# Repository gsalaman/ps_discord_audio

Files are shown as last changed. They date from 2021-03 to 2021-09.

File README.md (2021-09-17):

# Playstion/Discord Audio Mixer Project
This project provides a box that mixes together Audio and Microphone from both Playstation and Discord sources into a single headset. 

Quick Links:
* [Project Proposal](https://docs.google.com/document/d/1kymvg32hHtV9tEDY5p4hLi2L7wjIxDkjKmbJ4Tb4wR8/edit?usp=sharing)
* [Schedule](https://docs.google.com/spreadsheets/d/1bOIFvx7hpu0AlzfgVh9q8kjzmG0GHja3u-9B9gV9Qrc/edit?usp=sharing)
* [Journal](https://github.com/gsalaman/ps_discord_audio/blob/main/journal.md)
* [Design Document](https://docs.google.com/document/d/1ipFKIDMNCPuamUNVuetQo5jEzDj95vrXEs8RwQP3rsA/edit?usp=sharing)
* [Test Plan](https://docs.google.com/document/d/1uWEIeDPq-ZtmWTCWSF0HcOkNuqYgmgUuFNPxV6GTQaU/edit?usp=sharing)
* [Software Source (Arduino)](https://github.com/gsalaman/ps_discord_audio/tree/main/ghost_case_v1)
* [Hardware Source (Kicad & Gerber)](https://github.com/gsalaman/ps_discord_audio/tree/main/audio_quad_minimal)
* [User's Guide](https://docs.google.com/document/d/133C6y8KPKBfXd7hmt4fOLVRxKzTunB-pMatfn9UUioA/edit?usp=sharing)
* [Project Presentation](https://docs.google.com/presentation/d/1Z-V4jjkeFAulbqQNvLp17moSJGjj3tiSwEFrkb0hboE/edit?usp=sharing)

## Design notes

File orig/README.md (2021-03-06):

# ps_discord_audio
My notes for a playstation/discord audio mixer

Plugs are TRRS.  From the specs, sometimes Shield is GND, sometimes Mic.  Gonna need to measure phones (android and apple), PC, and playstation.  Just in case, could design in a jumper to route those two...

```
Mac, HTC headset, HTC phone:
------------------
Tip is L audio
R1  is R audio
R2 is GND
S  is Mic
```

## Simple Audio Mix:  a bunch of 470 ohm resistors:


## Next Steps
I'm gonna want gain.  I *could* use a 324, but the LM386 looks like it's custom made for what I want.  Cool amplifier link here:
https://www.circuitbasics.com/build-a-great-sounding-audio-amplifier-with-bass-boost-from-the-lm386/

Prototype with two channels, then summed with the resistors as above.  Implementation will have a dual gang potentiometers to hit both channels.

Will need to make a bunch of TRRS cables.  Buying them is $10 a pop, and each setup needs 2...or maybe even 3 if their headset doesn't have one.
Could do cable connected directly outta box to Discord and Playstation Controller, but I think I like the connector instead...seems like it's more robust as the cable will come out under stress (rather than breaking)

Want Mute Switch.

And, if we're doing this, I should have cool lights...an ATTINY85 and a couple LEDs.

### Proto parts needed
* TRRS Female connectors.  Have 7.
* Cable Parts:
  * TRRS Male Connectors.  If I churn out 10 boxes, I need 20 cables or 40 connectors. Start smaller.
  * Heat shrink
  * 4-wire cabyle itself
  * What's the cost effectiveness?
* LM386.   2 for proto.  JLCPCB for after that.
* Some sort of Mute Switch.  Can use SPDT for starters; 10 others for production.
* 2 Dual-Gang pots for Proto.  10 for production.
* 1000 uF cap x2
* .1 uF cap x4
* 10k resistor x2
* Have the 470 resistors for signal summming.
* 470 pF Cap x2
* 100 uF Electrolytic cap x2
* 10 uF Electrolytic cap x4

## Test #1
Build 1 of the "simple" amplifier circuit.  How does it sound?  Should be popping etc.  Gain of 20 okay?

## Test #2
Now make 2 of them, chained together with the 470 ohms.  Seperate gain works?  Can I drive both off one batt?  Can I move the 1000uF cap to *after* the sum?

## Test #3
More advanced circuit...build up both.  Significant sound quality increase?  

## Test #4
4 circuits, mixing all 4 channels.  Dual Pots.  Can I still get away with one batt?

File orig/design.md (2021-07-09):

# Playstation/Discord Audio Mix Box Design

## High Level Overview

## Hardware
Since I'm making multiple boxes, I'm going to do the hardware board as a custom PCB.  The various blocks:
* Battery and Power switch
* Audio Mixing
* Light Control 
* Microphone Routing and Mute Switch

### Overall Schematic


Note that I've got two different grounds:  
*  GND for the audio signal
*  GNDREF for power
This should help isolate the audio from "pops and clicks" due to any fluctuations on the power circuit.

The top section is our audio mix circut; almost identical to the prototype version, with the exception that the Mic signal goes through a mute switch (SW1).  The other pole of this mute switch goes to the ATTINY85 processor.

The bottom section is our ATTINY85 processor, with power and LED.

### Component Selection
#### Battery
I'm going to use a standard 2032 coin cell.  The following battery holders are available on Amazon:
https://www.amazon.com/gp/product/B08SQJJJNK/ref=ppx_yo_dt_b_asin_title_o09_s00?ie=UTF8&psc=1

#### Audio Cables and Jacks
All of the audio cables are going to be TRRS cables (Tip/Ring/Ring/Shield).  The following jacks are available on Amazon:
https://www.amazon.com/gp/product/B089222S84/ref=ppx_yo_dt_b_asin_title_o07_s00?ie=UTF8&psc=1

The pinout is as follows:
| pin | name | color | 
|-----|-----|-----|
| 2 | L | white |
| 3 | R | red |
| 4 | Gnd | Black |
| 1 | Mic | Green |

```
 2  3  4  1  ___
 __ __ __ __|
(__|__|__|__|
            |___
            
```

#### Power Switch
I'm using a simple SPST switch for power:
https://www.amazon.com/gp/product/B08JYV8HZ7/ref=ppx_yo_dt_b_asin_title_o01_s00?ie=UTF8&psc=1

#### Mute Switch
I need the mute switch to do two things:
* break the microphone path
* give the ATTINY a signal to detect whether we're muted or not.

Because of this, I'm choosing a Dual-Pole-Single-Throw switch.  One end goes through the Mic path, one end goes to the ATTINY.
https://www.amazon.com/gp/product/B07QS8K8T2/ref=ppx_yo_dt_b_asin_title_o09_s00?ie=UTF8&psc=1

Note that the ATTINY does not have pull-up resistors on it's input, so I've got R5 on the board for that purpose.

#### LED
I'm using a custom board with a single WS2812 LED.  It's able to be driven by the coin cell and the ATTINY.  The WS2812 will let me change colors on the LED.

### PCB Layout
The final PCB layout is as follows:


Note I'm only going Through-Hole parts here; no SMT assembly from the PCB vendor.

## Software
The ATTINY will have two modes of operation:
* When the mute switch is active (Muted), it'll blink the LED red.
* When the mute switch is not active (Not Muted), it'll cycle the LED through colors.

I'll be using the Arduino environment to program the ATTINY85.

### High Level Software Overview
I'll use Adafruit's NeoPixel library to program the LED.  

I'm going to use a global "tick_number" indicator to count time.   

I'll have globals for the Red/Green/Blue pixel values for when we're cycling through colors.  

The "setup" function will set up the  pins for Mute and LED.  

The "loop" function will read the Mute button, and choose between the following functions:
* Flash the LED red (muted)
* cycle through colors (non-muted)

"Loop" will also need to keep track of the last state of the mute button.  This is because when we first turn OFF mute (Un-mute), we want the cycle colors to reset to a known starting point.

### Muted Operation
We'll use the "tick_number" and a modulus funcition to alternate between setting the LED to all red or off.  I'll experiement with time values to see what looks good.

### Un-Muted Operatoin
This one will be a little tricker.  Here's the cycle algorithm:
```
Start with the LED Blue.
Step 1: Slowly decrease the Blue RGB value and increase the Green RGB value until the LED is all Green.
Step 2: Slowly decrease the Green RGB value and increase the Red RGB value until the LED is all Red.
Step 3:  Slowly Decrease the Red RGB value and increase the Blue RGB value until the LED is all Blue.
```
To determine which "step" we're on, I'll cycle the tick number.  Since each color value is going from 255 to 0 (or vice versa), I have 256 "ticks" in each step.

## Plastics
I'm going to design the case in three pieces:
* The "shell" will be the walls and the top, with holes for switches, heat-sets (to attach the bottom), jacks and the ghost.  I'll label the Jacks via embossed letters.
* The "bottom" will be a simple rectange that gets screwed onto the bottom of the case (and gives the user access to replacing the battery).
* The "Ghost" will be a contrasting color, modelled after destiny's Ghost.  I'll use a seperate piece of diffusing acrylic (laser-cut) to "spread out" the light of the led.  This will be glued onto the top.

Onshape files can be found here:
https://cad.onshape.com/documents/8eac8258773643f40666c139/w/5a93e26a0a6b1984f3ee80b1/e/b21e37a20e72b8d13801b5df

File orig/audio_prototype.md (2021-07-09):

# Prototyping Notes and Plan

Before I jump into my design, there are some prototyping things I need to do.

I'm comfortable with the ATTINY driving an LED and also using a mute switch.  Ready to go to design on those.

I need to figure out how to mix the audio signals together.  I have two options, listed below.

## Prototype Plan
### Simple Audio Mix:  a bunch of 470 ohm resistors
The easiest solution is to do passive mixing...basically connecting each channel together with resistors.  Looking online, the resisitor value is dependent on the output impedence, and looks like 470 ohm will do the trick for my headphone example.  
Here is the circuit:


Pros:  Very simple!  Not too many components.  Doesn't require power.

Cons:  I'm going to lose a little volume from each channel.

### Mix with Gain
If I want to add gain to the system, I'm going to need an amplifier.  In the past I've used a generic LM324 Op Amp, but the LM386 looks like it's custom made for what I want.  Cool amplifier link here:
https://www.circuitbasics.com/build-a-great-sounding-audio-amplifier-with-bass-boost-from-the-lm386/

I'm going to do a bread-boarded prototype with two channels, then summed with the resistors as above.  Implementation will have a dual gang potentiometers to hit both channels.

Pros:  able to control gain via the knobs on the box rather than going to PS & Discord to seperately tweak the levels.

Cons:  MUCH more complicated.  Requires a bigger battery to drive (9v?).

## Prototype Results:
* Simple audio mix worked well.  Audio loss was able to be compensated by Discord and PS apps on either side.
* The gain prototype was cool!  May go this route for a phase 2, but for now, I'm gonna go with the simpler solution.

## Next Step:  Write design document.

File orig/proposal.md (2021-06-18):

# Playstation/Discord Audio Mixer Box

## Problem Statement
I'm an avid "Destiny" gamer.  This game spans multiple platforms, and I've got people I play with on both the PC and Playstation platforms.
Communication is key when running this game; there are actions that need to be communicated precisely.  While Desitiny supports an "in-game" chat, 
the quality of the voice is severly lacking.  Because of this, most Destiny players run a different application for voice chat:
* Discord for the PC
* "Party Chat" on the Playstation

There is currently no cross-play functionality.  If you are on a PC, you must play with other PC players; you can't play with people running Destiny on a Playstation.  
However, cross-play has been announced, and will arrive in September, allowing PC and Playstation players to play together.

The problem is that there is no cross-play voice chat functionality (except for the limited game-chat).  My proposal is to make a box that allows a Playstation player to 
hook into Discord, mixing the audio from both Discord and the Game into the player's headset.

## Proposed Implementation
System Block Diagram below:
Discord Box Block Diagram

The "Discord" box can be any device using Discord...phone, tablet, laptop, desktop, etc.

The audio channels will be mixed passively between the Playstation controller and Discord box.

Microphone signals only need to go to the Discord app, as we won't be using Playstation Party Chat.  While we could rely on mute from the Discord box, we'll implement a hardwired mute switch in the microphone path for convenience.

To "spice up" the look of the box, we're going to design in a Destiny "ghost" with a light-up eye.  We'll have a simple Microprocessor driving that eye with two modes:
* In normal mode, the colors will cycle.
* When the box is muted, the eye will flash red

To power this processor, we'll use a simple coin-cell battery.

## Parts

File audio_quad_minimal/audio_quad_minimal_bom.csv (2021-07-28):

Comment | Designator | Footprint | LCSC Part Number
.1 uF | C3,C4,C7,C8 | 603 | C14663
1000uF | C1,C2,C5,C6 | SMD-ECAP-10x10 | C249474
470 ohm | R2,R3,R4,R5 | 603 | C23179
10 ohm | R6,R7,R8,R9 | 603 | C22859
LM386 | U1,U2,U3,U4 | SOIC-8_3.9x4.9x1.27P | C23573
220 ohm | R1 | 603 | C22962
pwr_led | D1 | 805 | C84256

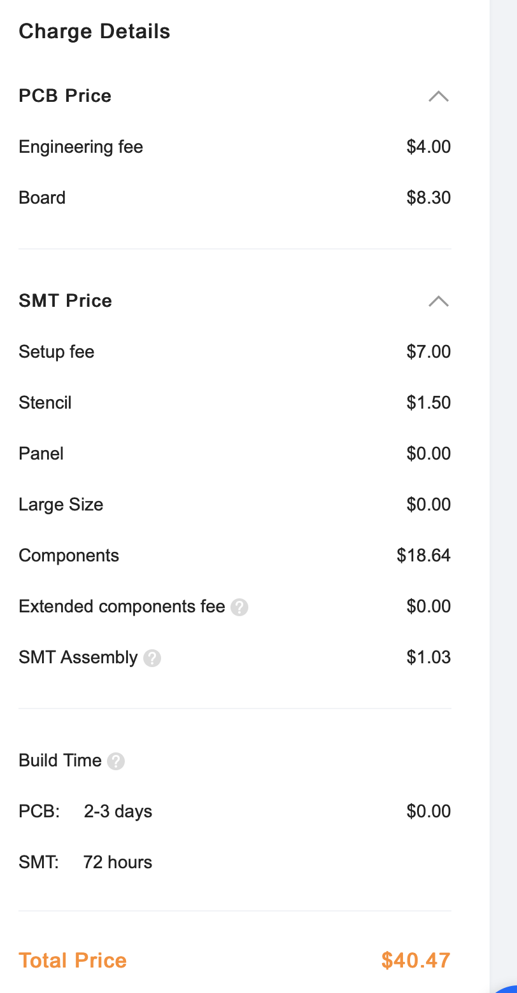
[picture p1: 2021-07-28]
audio_quad_minimal/cost for 10.png

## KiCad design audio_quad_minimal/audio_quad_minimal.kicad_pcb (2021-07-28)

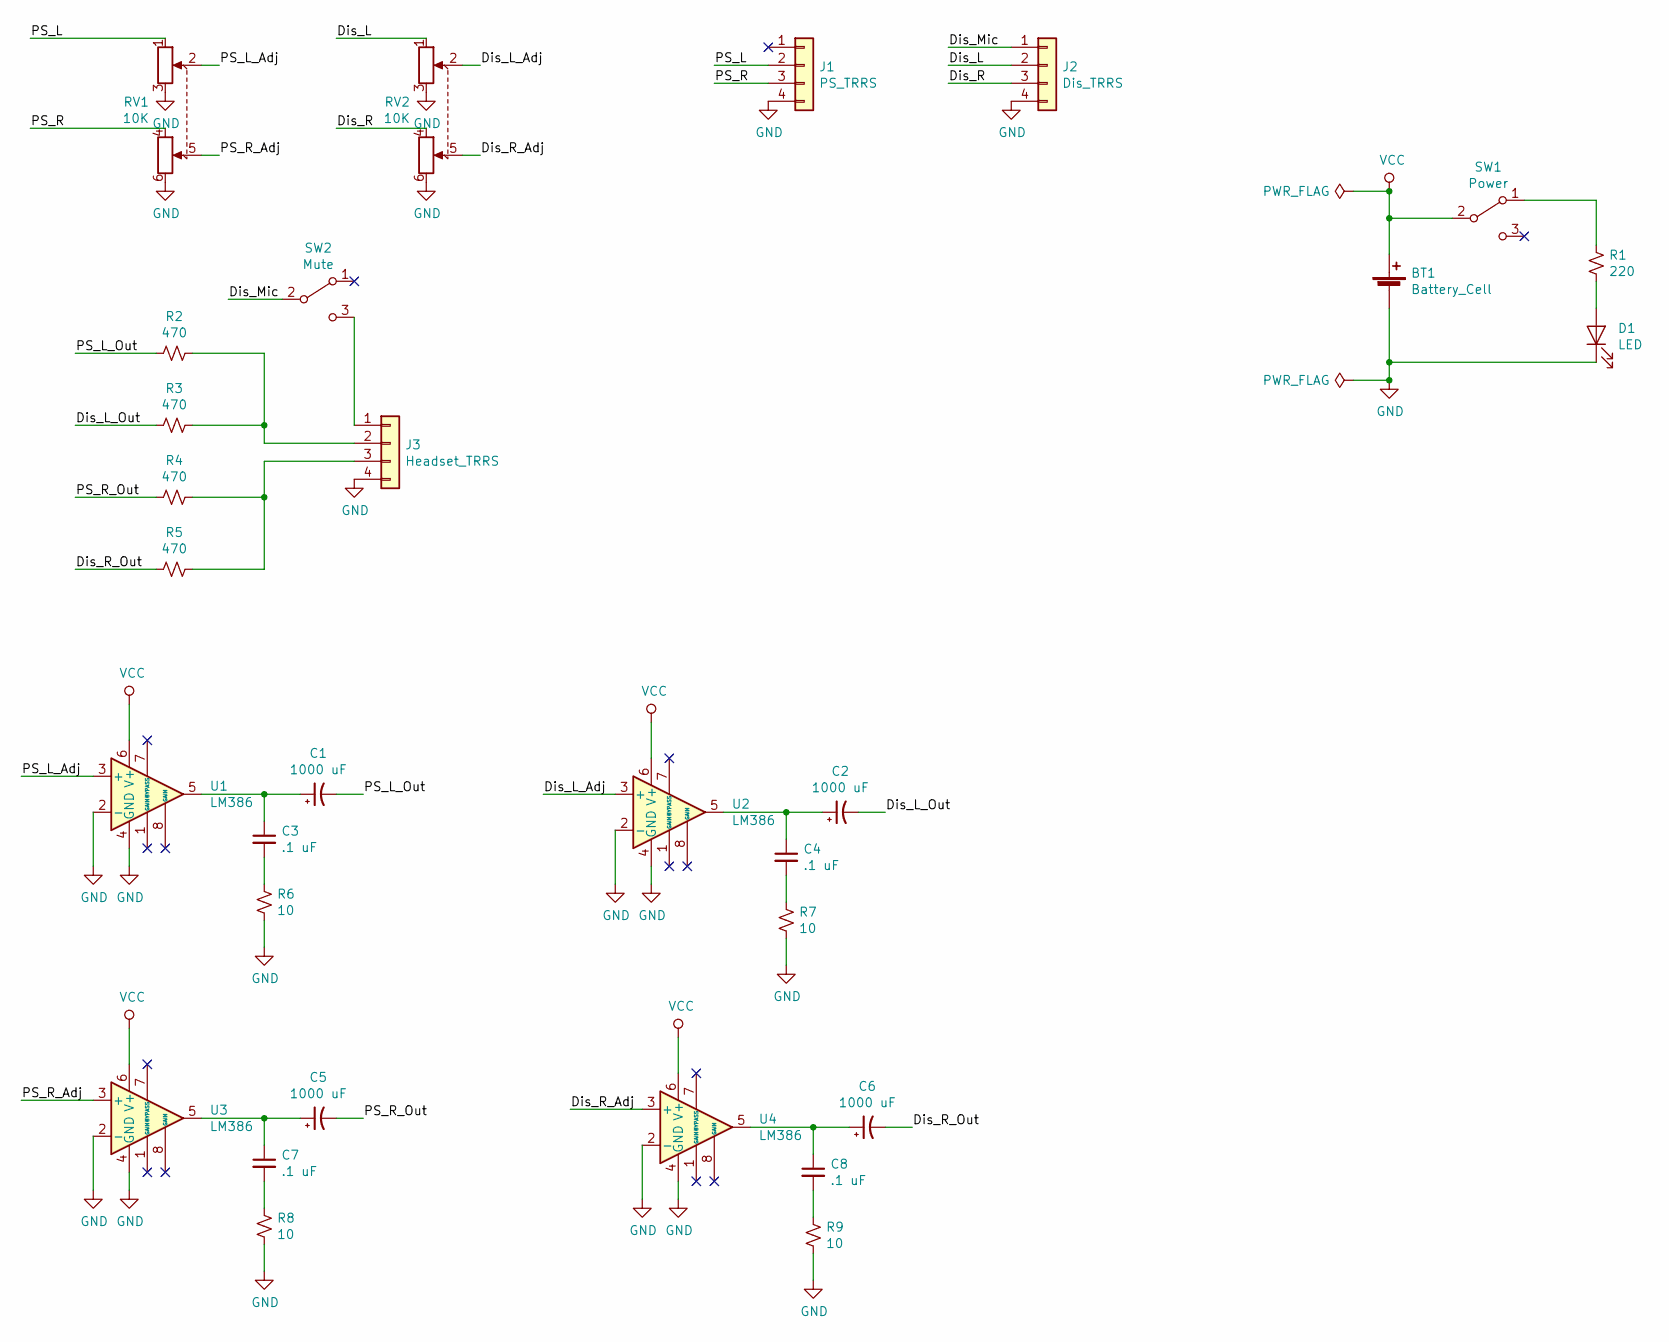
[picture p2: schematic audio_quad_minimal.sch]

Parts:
BT1: Battery_Cell; PinHeader_1x02_P2.54mm_Vertical
C1, C2, C5, C6: 1000 uF; CP_Elec_10x10
C3, C4, C7, C8: .1 uF; C_0603_1608Metric
D1: LED; LED_0805_2012Metric
J1: PS_TRRS; PinHeader_1x04_P2.54mm_Vertical
J2: Dis_TRRS; PinHeader_1x04_P2.54mm_Vertical
J3: Headset_TRRS; PinHeader_1x04_P2.54mm_Vertical
R1: 220; R_0603_1608Metric
R2, R3, R4, R5: 470; R_0603_1608Metric
R6, R7, R8, R9: 10; R_0603_1608Metric
RV1, RV2: 10K; PinHeader_2x03_P2.54mm_Vertical
SW1: Power; PinHeader_1x03_P2.54mm_Vertical
SW2: Mute; PinHeader_1x03_P2.54mm_Vertical
U1, U2, U3, U4: LM386; SOIC-8_3.9x4.9mm_P1.27mm

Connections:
/Dis_L: J2.2, RV2.1
/Dis_L_Adj: RV2.2, U2.3 (+)
/Dis_L_Out: C2.2, R3.2
/Dis_Mic: J2.1, SW2.2 (B)
/Dis_R: J2.3, RV2.4
/Dis_R_Adj: RV2.5, U4.3 (+)
/Dis_R_Out: C6.2, R5.2
/PS_L: J1.2, RV1.1
/PS_L_Adj: RV1.2, U1.3 (+)
/PS_L_Out: C1.2, R2.2
/PS_R: J1.3, RV1.4
/PS_R_Adj: RV1.5, U3.3 (+)
/PS_R_Out: C5.2, R4.2
GND: BT1.2 (-), D1.1 (K), J1.4, J2.4, J3.4, R6.2, R7.2, R8.2, R9.2, RV1.3, RV1.6, RV2.3, RV2.6, U1.2 (-), U1.4 (GND), U2.2 (-), U2.4 (GND), U3.2 (-), U3.4 (GND), U4.2 (-), U4.4 (GND)
unnamed: C1.1, C3.1, U1.5
unnamed: C2.1, C4.1, U2.5
unnamed: C3.2, R6.1
unnamed: C4.2, R7.1
unnamed: C5.1, C7.1, U3.5
unnamed: C6.1, C8.1, U4.5
unnamed: C7.2, R8.1
unnamed: C8.2, R9.1
unnamed: D1.2 (A), R1.2
unnamed: J3.1, SW2.3 (C)
unnamed: J3.2, R2.1, R3.1
unnamed: J3.3, R4.1, R5.1
unnamed: R1.1, SW1.1 (A)
VCC: BT1.1 (+), SW1.2 (B), U1.6 (V+), U2.6 (V+), U3.6 (V+), U4.6 (V+)

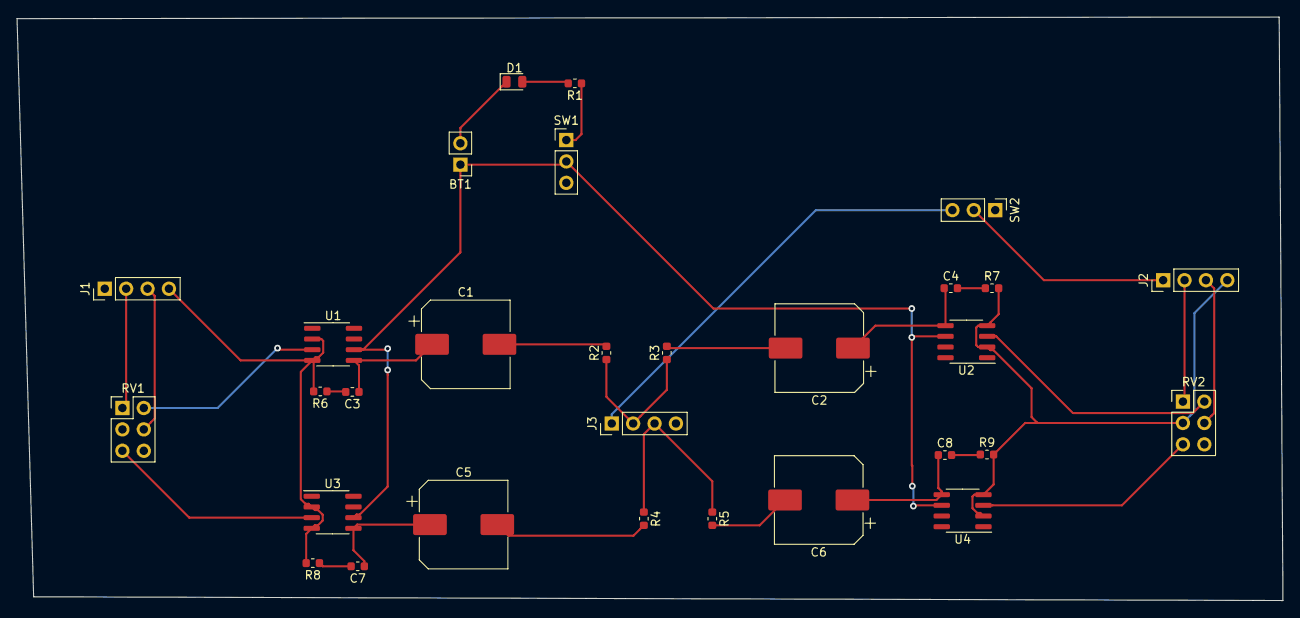
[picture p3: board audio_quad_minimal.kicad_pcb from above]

Board: 2 copper layers, 150.3 x 69.3 mm, 30 parts (0 on the bottom side), 28 nets.

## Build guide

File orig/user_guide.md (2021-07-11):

# Overview
top
topv2

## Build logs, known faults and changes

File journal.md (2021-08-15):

# 3/1/21
First order of buisness: see how the plugs are wired.  

From the specs, sometimes Shield is GND, sometimes Mic. Gonna need to measure phones (android and apple), PC, and playstation. Just in case, could design in a jumper to route those two.  Diagram below:

```
 T  R1 R2  S ___
 __ __ __ __|
(__|__|__|__|
            |___

Measured on my Mac and HTC headset:
------------------ 
Tip is L audio
R1  is R audio
R2 is GND
S  is Mic
```
I'm a little worried that the iPhone is gonna be wired differently, as Apple tends to do things their own way...but the Mac is wired the same as the android phone (and playstation controller), so that's less risk.  Will send a prototype out to Lamonte (who has iPhone) and let him test it.

# 3/4/21

Before I jump into my design, there are some prototyping things I need to do.

I'm comfortable with the ATTINY driving an LED and also using a mute switch.  Ready to go to design on those....I'm gonna reuse the same "cycle" code I've previously done for the ATTINY before, and add a second "flashing red" state for mute.  

I need to figure out how to mix the audio signals together.  I have two options, listed below.

### Simple Audio Mix:  a bunch of 470 ohm resistors
The easiest solution is to do passive mixing...basically connecting each channel together with resistors.  Looking online, the resisitor value is dependent on the output impedence, and looks like 470 ohm will do the trick for my headphone example.  
Here is the circuit:


Pros:  Very simple!  Not too many components.  Doesn't require power.

Cons:  I'm going to lose a little volume from each channel.

### Mix with Gain
If I want to add gain to the system, I'm going to need an amplifier.  In the past I've used a generic LM324 Op Amp, but the LM386 looks like it's custom made for what I want.  Cool amplifier link here:
https://www.circuitbasics.com/build-a-great-sounding-audio-amplifier-with-bass-boost-from-the-lm386/

I'm going to do a bread-boarded prototype with two channels, then summed with the resistors as above.  Implementation will have a dual gang potentiometers to hit both channels.

Pros:  able to control gain via the knobs on the box rather than going to PS & Discord to seperately tweak the levels.

Cons:  MUCH more complicated.  Requires a bigger battery to drive (9v?).

## Simple Audio Mix Prototype:
Picture of the breadboarded circuit:


Results: worked well.  Audio loss was able to be compensated by Discord and PS apps on either side...but there still was loss.

# 3/7/21
Next iteration: single channel gain stage combining.  Specifically, taking the R channel from two sources (PS and Discord), applying seperate gains (controlled by the two knobs), and then combining the output signal like in the previous experiment.  Picture of the breadboarded prototype:


Results:  worked fairly well....but going to two channels means circuitry gets a little more complicated...and I'm worried about pops and clicks (got a few just on the breadboard)  

Plan:  I'm gonna shelve this one, and proceed with the simple mix for our product.

# 3/11/21
Soldered up prototype to send out to Lamonte for iPhone testing:


# 3/20/21
Spun a simple case...pics below:




# 3/30/21
Prototype box mailed out to Lamonte!

# 4/2/21
Tested the box with Lamonte...me on the breadboarded version, him with the prototype via iPhone.

IT WORKED!!!

Now, time to spin the schematic via kicad.

# 4/10/21
Board spin complete; sent to JLCPCB.

# 4/11/21
Plastics thoughts:
* Gotta be able to get to the battery...meaning I want the bottom removable via heat-sets.
* Need to label the jacks.  In a pinch, I can do the label maker like with Lamonte's board...but I want something a little "better".  Gonna try embossing the letters vertically...I think the uPrint can deal with that.
* Ideally, I want the "ghost" a different color...meaning a different plastic print.  I'll design it in so that there's a "shelf" on the top for it to fit into....and I need a square hole for the LED board to shine through.
* For the ghost "eye", I'm just gonna cut a piece of 1/8 wood from the laser cutter (cheaper!) and glue it in place.  If I need it, I'll use a piece of that whiteish LED diffusing acrylic.

# 4/12/21
Stopped by Dawson:  printed outer shell.  Yellow is the color in the printer.

# 4/13/21
Shell happy...uPrint in use by others, so I printed the ghost on the Raise3D.  

Now I just need the boards to come back...

# 4/15/21
JLCPCB build complete...boards on their way back to me.

# 4/21/21
Got the boards back from JLCPCB!!!  Assembly pics below.

### The board:


### The other components:


Note that the rocker switch for the mute is already in the case...I did a test fit, as this one "snaps in".  Made soldering it a little more challenging...more on that below.

### The ghost:  

I used a black sharpie to "darken" the eye.

I used 5 minute epoxy to glue it all together...I'm gonna want to tweak the eye size (make it bigger) and "shield" size (make it even bigger) to make everything fit well.

### TRRS Jacks
The TRRS jacks were tricky.  They've got a 1-4 number on each pin, corresponding to which of the Tip/Ring/Shield they're connected to.  You'd think that 1 would be tip, 2 the next ring, 3 the next, and 4 shield....but no!  Here's the actual pinout:
| pin | name | color | 
|-----|-----|-----|
| 2 | L | White |
| 3 | R | Red |
| 4 | Gnd | Black |
| 1 | Mic | Green |

```
 2  3  4  1  ___
 __ __ __ __|
(__|__|__|__|
            |___
            
```
Here they are, prior to assembly:



Soldering the wires onto the pins without them shorting is tricky...I found it best to bend the wire into a "J", thread it into the jack hole so the wire is in the middle/core, do the soldering, then trim the excess of the J.  That gives you this:



### Board Front
Do through-hole soldering for the mixing and pull-up resistors, and solder on the 3 jacks:



LED board and power switch go on next...some of those wires are under the battery holder.  



Note that I've also done 4 wires on the two poles of the mute switch...a little tricky to get into the case to hit these.  Next time, I do that soldering first, then snap the switch into place.

### Board Back
Then do the battery holder and socket for the ATTINY on the other side.



### Last Steps
Next, test fit the board into the case.  Get the bends for all the wires about right...and then you can solder on the other side of the mute switch.

Do a "final positioning" of the LED to make sure it's centered in the diffusing plastic, and then glue the ghost on top of the case.

The final product:



# 4/27/21
Today's mission:  Plastics colors!

I'm going to need to print at least 6 more cases for the clan...so that's a fair amount of plastics.

The uPrint is definitly the most solid, dependable printer.  Dawson has Orange, Red, Yellow, and Green...and you can order black.   Trouble here:  the spools are $180 each...a little pricey.

You can get LOADS of colors from Matterhackers for the Raise3d....and they're much cheaper...$20 a spool.  Here's what I'm gonna do:
* use [grey](https://www.matterhackers.com/store/l/175mm-pla-filament-grey-1-kg/sk/MPL0Q8ZD) for the case
* There's a cool [silver/blue](https://www.matterhackers.com/store/l/silky-teal-mh-build-series-pla-filament-175mm-1kg/sk/M4042W07) for the ghost.

I'll need support for the case, but the Raise3D can do water-soluable PVA.

# 5/12/21
Started printing in bulk.  Got one grey top done:



Sizing looks good; ready to go in bulk!

# 5/16/21
Lara offered to help with assembly...we soldered up a bunch of boards today.  Still waiting for the plastics for full assembly.  Pics below:





# 5/19/21
Print failures!!! 





I think its cause I did 50% infill and the layers didn't quite bond.  Gonna try 100% next time...

# 5/21/21
More assembly!  Still don't have the cases, but were able to put together a bunch more boards.  Pics:





# 5/28/21
Tried another print...and had another failure!  Much like the one from the 19th...so it's not infill.  Hmmmm...

# 6/1/21
Tried another case print with Raise3D brand white just to change a variable...it mostly worked:



A little stringy-ness with the PVA...but the case is mostly smooth.

# 6/4/21
More print issues!  Tried just doing the ghost with the silky blue, and it stops extruding about half way through.  (second time caused a big jam)

Here's a pic of where one of them failed:



Plan:  do full printer calibration with Chris on monday.

# 6/7/21
Chris and I are doing a full printer calibration...left-and-right nozzle heights, offsets, build leveling...anything that needs to be done.

Had some challenges:
* the Z-offset thumbscrew doesn't seem to do anything...there's a pin that goes to a sensor, but changing the thumbscrew doesn't change the pin.  Chris and I did the "coarse adjust" (not recommended) to get everything happy.
* When doing right nozzle height, it wasn't able to go up  high enough.
* The silky blue PLA still has the extrude problem...gets part way through the print, then jams.

I put in tickets with Raise3D and MatterHackers.

# 6/8/21
Matterhackers ticket response was to change temp and flowrate.  Tried that, same effect...material stops extruding.

Raise3D answers:
* Pin sometimes gets stuck.  Yup...that was it.
* Played around with heatsink position on right nozzle...got that happy as well.

Can now get the offset prints happy via dual extrude...so hopefully that'll help with the PVA.

# 6/10/21
Matterhackers had more experiments for me to try....but none of them were happy.  They refunded my $ on the spool.  Raise3D confirmed that matterhackers was having issues.  

Soooooo....I've got Raise3D filament in grey and blue ($35 each) to build out the ghosts.  Not the cool silky-blue, but if it extracts well, I'll deal...

# 6/13/21
Raise3D filament arrived.  And it just works:



Had some dual extrude thoughts:
* Instead of using wood for the ghost eye, I can do a blue/black dual extrude to do the whole ghost at once...which will mean I shouldn't have a gap between the eye and ghost
* I can use dual extrude for the jack labels...and if I'm going that route, I can use that to personalize the cases!!!!
* This means I need to use PLA as support rather than PVA....but that should be doable.

Ordering black PLA for the eyes...

# 6/17/21
Notes on support:  0.2 mm offset seems to be about right to make the fillet happy.  However, that makes taking out the jack holes hard...you have to drill them.  I'm okay with that.

# 6/23/21
Printing ghosts:


The harvest:


# 6/25/21
Time lapse of Pocket's case:
https://glennsalaman.smugmug.com/Other/n-FVHJP5/Dawson/i-Tjtmr7S

# 7/09/21
Finished assembly...here's the final output:





And...in action:
https://drive.google.com/file/d/1iL1jrGGfeoajQjLoZIwszLVyoZmZPBB2/view?usp=sharing

# 7/13/21
Cases shipped!

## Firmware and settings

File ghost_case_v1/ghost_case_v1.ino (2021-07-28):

/*===========================================================
 * Single LED control for Ghost Mix Case.
 * Cycle through colors on LED unless Muted...then
 * Flash Red.
 */
 
#if defined(__AVR_ATmega328P__)
//#define PLATFORM_UNO
#elif defined(__AVR_ATtiny85__)
#define PLATFORM_TINY
#else
#error "PLATFORM UNSUPPORTED"
#endif
#include <Adafruit_NeoPixel.h>

// Which pin to use for DualRingLED control
#ifdef PLATFORM_TINY
#define LED_PIN    4 // tiny pin 3 = D4
#define MUTE_PIN   0  // tiny pin 6 = D0
#else
#define LED_PIN    5
#define MUTE_PIN   4
#endif

#define NUMPIXELS  1



Adafruit_NeoPixel pixels = Adafruit_NeoPixel(NUMPIXELS, LED_PIN, NEO_GRB+NEO_KHZ800);

#define COLOR_RED     0xFF0000
#define COLOR_GREEN   0x00FF00
#define COLOR_BLUE    0x0000FF
#define COLOR_MAGENTA 0xFF00FF
#define COLOR_YELLOW  0xFFFF00
#define COLOR_CYAN    0x00FFFF
#define COLOR_BLACK   0
#define COLOR_WHITE   0xFFFFFF

// GLENN:  should these be uint8_ts?
int red=0;
int blue=0xff;
int green=0;

int tick_number=0;

void setup()
{

    #ifdef PLATFORM_UNO
    Serial.begin(9600);
    Serial.println("Inited");
    #endif

    pinMode(MUTE_PIN, INPUT);
    pinMode(LED_PIN, OUTPUT);
    
    pixels.begin();

    pixels.setPixelColor(0,COLOR_BLUE);
    pixels.show();
}

#define COLOR_DELAY_US 10000
void cycle_colors(int tick_number)
{ 
  // Function gets called every 10 ms, with a tick index.
  // Ticks 0 to 255 go from blue to green.
  // Then we pause for 1 second (100 more ticks...256 to 356)
  // Then 357 to 612 we go from green to red.
  // Then we pause for 1 second (100 more ticks...613 to 713)
  // Then 714 to 969 we go red to blue.
  // Then 970 to 1070 we pause.

  // reset
  if (tick_number == 0)
  {
    #ifdef PLATFORM_UNO
    Serial.println("RESET");
    #endif
    
    green = 0;
    blue = 0xff;
    red = 0;
  }
  // step 1:  blue to green
  if ((tick_number > 0) && (tick_number < 256))
  {
    green++;
    blue--;
    pixels.setPixelColor(0, red, green, blue);
    pixels.show();

    #ifdef PLATFORM_UNO
    Serial.print("b-g: ");
    Serial.print(red); Serial.print(" "); 
    Serial.print(green); 
    Serial.print(" "); 
    Serial.println(blue);
    #endif
  }

  // step 2:  green to red.
  if ((tick_number > 356) && (tick_number < 612))
  {
    green--;
    red++;
    pixels.setPixelColor(0, red, green, blue);
    pixels.show();

    #ifdef PLATFORM_UNO
    Serial.print("g-r: ");
    Serial.print(red); Serial.print(" "); 
    Serial.print(green); 
    Serial.print(" "); 
    Serial.println(blue);
    #endif
    
  }

  // step 3:  red back to blue
  if ((tick_number > 713) && (tick_number < 969))
  {
    blue++;
    red--;
    pixels.setPixelColor(0, red, green, blue);
    pixels.show();

    #ifdef PLATFORM_UNO
    Serial.print("r-b: ");
    Serial.print(red); Serial.print(" "); 
    Serial.print(green); 
    Serial.print(" "); 
    Serial.println(blue);
    #endif
  }

  // any other tick number, we don't do anything.
}

void flash_red(int tick_number)
{
  int tick_mod;

  tick_mod = tick_number % 200;
  if (tick_mod < 100)
  {
     pixels.setPixelColor(0, 0, 0, 0);
  }
  else
  {
    pixels.setPixelColor(0,255,0,0);
  }
  pixels.show();
}

void loop(void)
{ 
  static int last_mute=HIGH;
  int        curr_mute;

  curr_mute = digitalRead(MUTE_PIN);
  
  if (curr_mute == HIGH)
  {
    flash_red(tick_number);
    tick_number++;
    if (tick_number > 400) tick_number == 400;
  }
  else
  {  
    if (last_mute == HIGH)
    {
      // Just turned off the mute.  Reset our eye vars
      last_mute = LOW;
      tick_number = 0;
      red = 0;
      green = 0;
      blue = 0xFF;
    }
    cycle_colors(tick_number);
    tick_number++;
    if (tick_number > 1070) tick_number = 0;
  }

  delay(5);
}

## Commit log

2021-07-28 Adding Software and Hardware assets
    [audio_quad_minimal-B_Cu.gbr, audio_quad_minimal-B_Mask.gbr, audio_quad_minimal-B_Paste.gbr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]
2021-08-15 migrating prototype doc to a journal
